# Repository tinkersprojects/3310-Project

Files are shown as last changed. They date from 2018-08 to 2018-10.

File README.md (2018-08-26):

# 3310 Project
The goal of the project is to make a working Nokia 3310 that works with today's tech. The device will be as similar as the original including the screen and body (case). It is unknown what process will be in the finished device but the first will have an ESP32. The ESP32 has both Bluetooth and WiFi which will be used to connect to a smartphone as an extension accessory. 

From the Nokia 3310, the user will be able to make/receive calls and SMS/text messages as well as play original games and all other good features. Additional features like social networking will come later. A micro USB port is used for charging, programming and debugging of the ESP32.

This first prototype is very basic to see which areas would need the most amount of work and to see if this project is worth continuing. There are features missing and features that will not be apart of the device. This prototype will look mostly at getting the LCD, keypad and Bluetooth/WiFi working.

**Get involved, [contact me](https://tinkersprojects.com/contact-me/)**

**See my other projects, [https://tinkersprojects.com/](https://tinkersprojects.com/)**

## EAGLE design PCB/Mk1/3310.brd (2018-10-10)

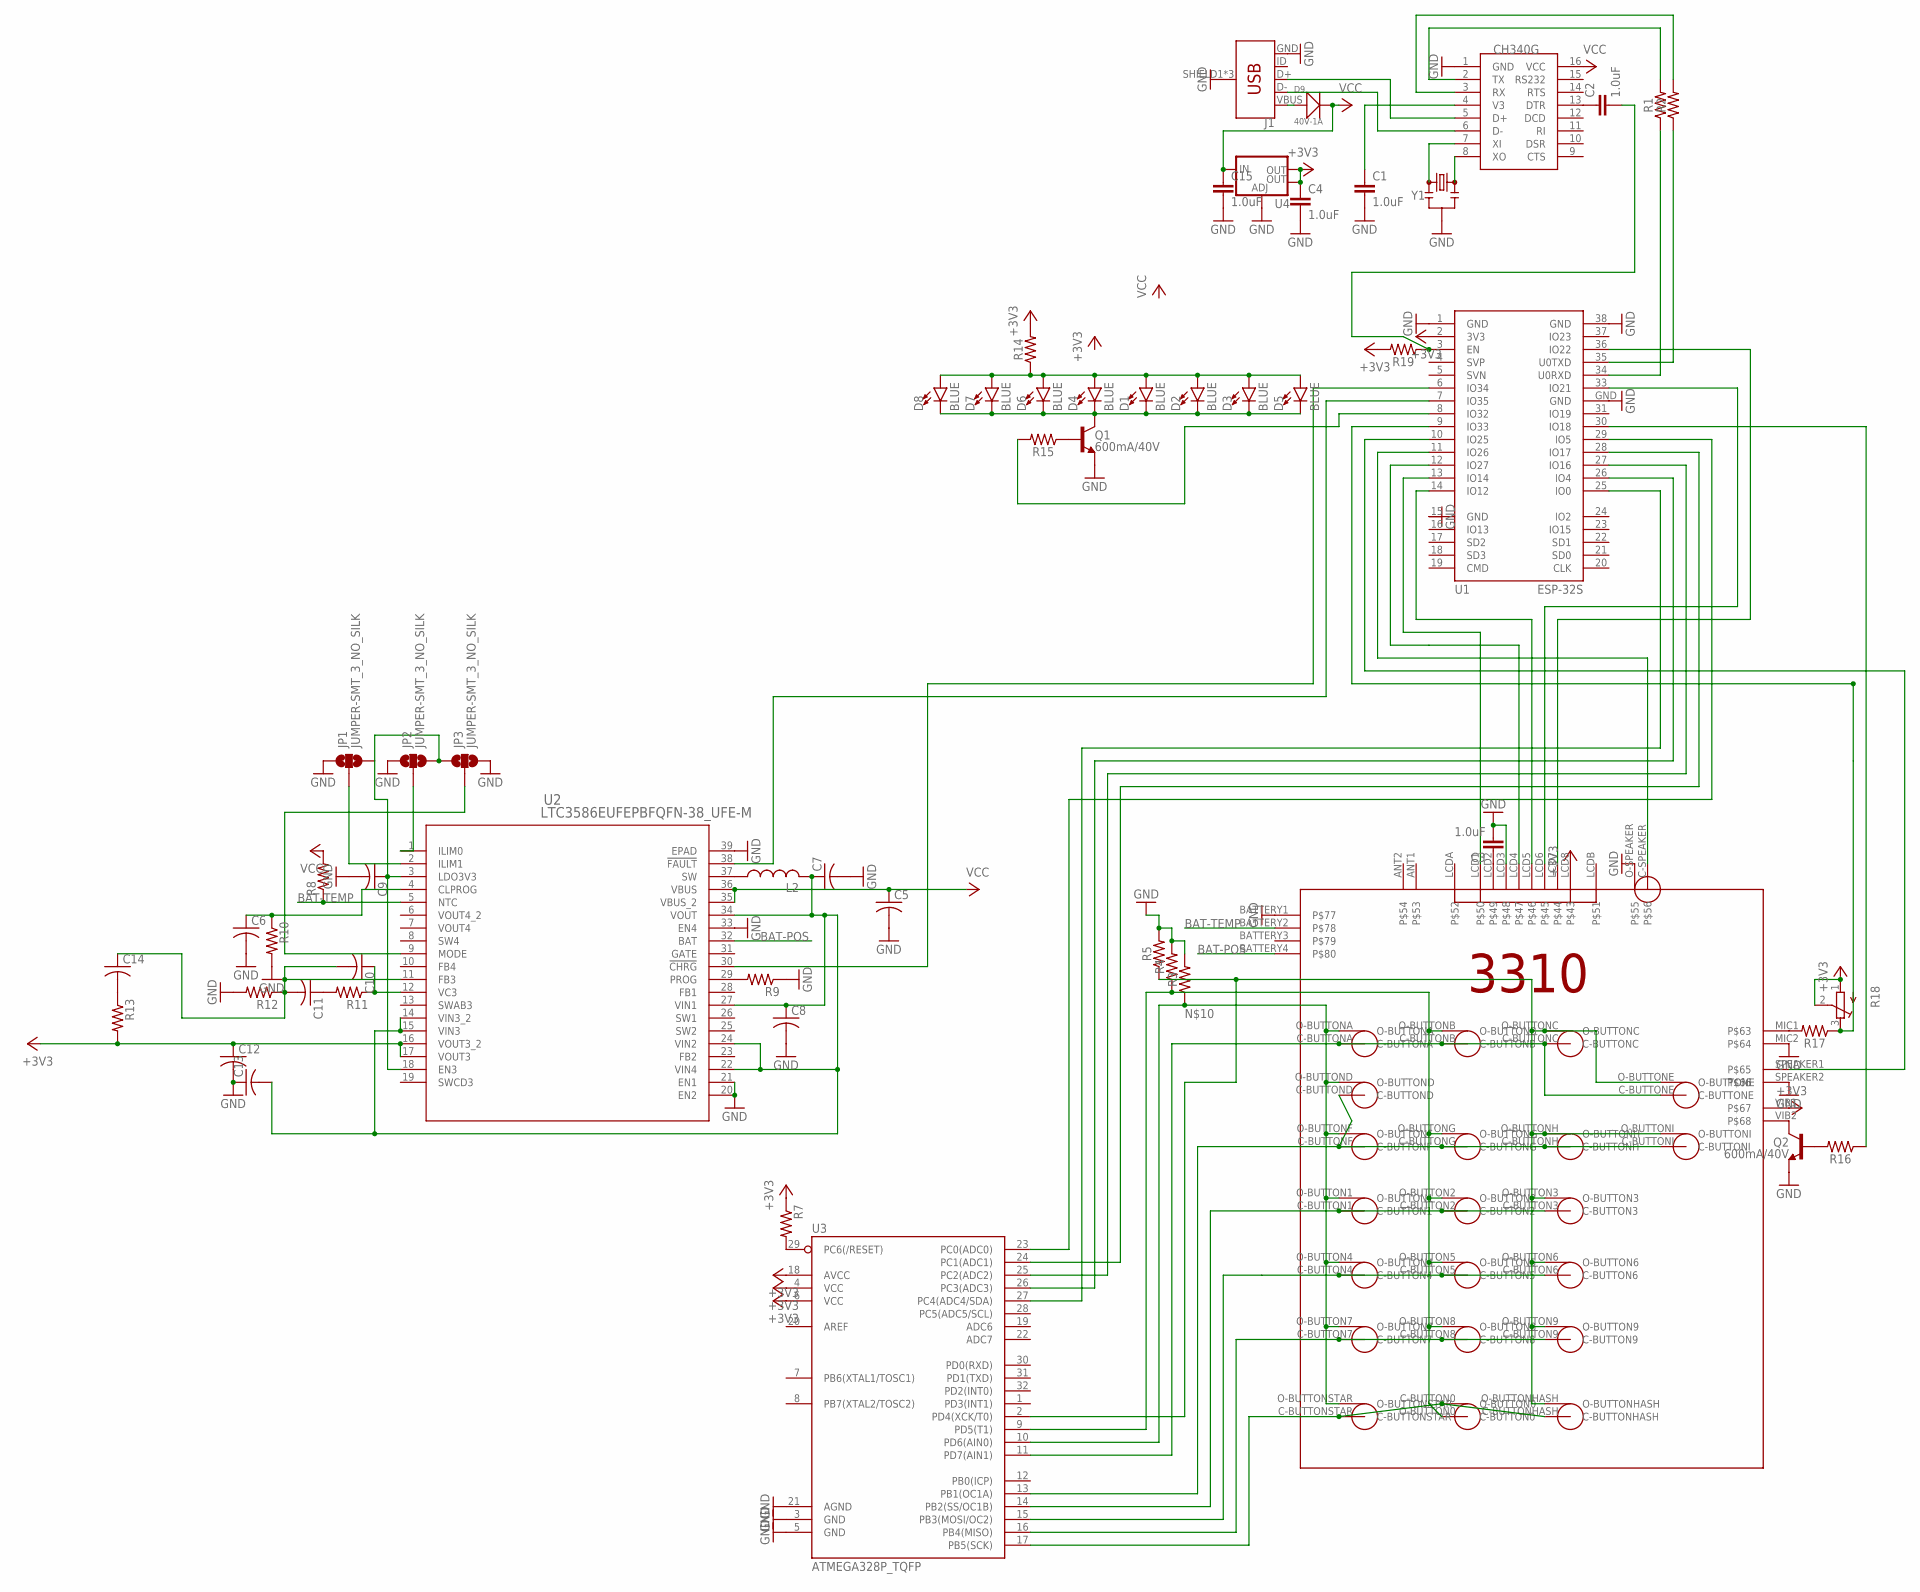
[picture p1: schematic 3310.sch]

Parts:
C1, C2, C3, C4, C15: 1.0uF; 0805
C5, C6, C7, C8, C9, C10, C11, C12, C13, C14: C-USC0805K; C0805K
D1, D2, D3, D4, D5, D6, D7, D8: BLUE; LED-1206
D9: 40V-1A; DO-214AC
J1: USB_MICRO-BREDUCED_PASTE; USB-B-MICRO-SMD_RED_PASTE
JP1, JP2, JP3: JUMPER-SMT_3_NO_SILK; SMT-JUMPER_3_NO_SILK
L2: L-USL3216C; L3216C
Q1, Q2: 600mA/40V; SOT23-3
R1, R2, R3, R4, R5, R14, R15, R16, R17, R19: 0805
R7, R8, R9, R10, R11, R12, R13: R-US_R0805; R0805
R18: R-TRIMM3103; RTRIM3103
U1: ESP-32S
U2: LTC3586EUFEPBFQFN-38_UFE-M; QFN-38_UFE-M
U3: ATMEGA328P_TQFP; TQFP32-08
U4: V_REG_LM1117SOT223; SOT223
U$1: 3310NOJACKANDSIM
U$2: CH340G; SOIC16
Y1: RESONATORSMD-3.2X1.3; RESONATOR-SMD-3.2X1.3

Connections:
+3V3: C4.1, C12.1, R7.1, R13.2, R14.2, R18.1 (A), R18.2 (S), R19.2, U1.2 (3V3), U2.16 (VOUT3_2), U2.17 (VOUT3), U3.4 (VCC), U3.6 (VCC), U3.18 (AVCC), U4.2 (OUT), U4.4 (OUT), U$1.LCD8, U$1.VIB1
BAT-POS: U2.32 (BAT), U$1.BATTERY4
BAT-TEMP: R8.1, U2.5 (NTC), U$1.BATTERY2
GND: C1.2, C3.2, C4.2, C5.2, C6.2, C7.2, C8.2, C9.2, C12.2, C13.1, C15.2, J1.GND, J1.SHIELD1 (SHIELD), J1.SHIELD2 (SHIELD), J1.SHIELD3 (SHIELD), JP1.1, JP2.1, JP3.3, Q1.2 (E), Q2.2 (E), R3.2, R4.2, R5.2, R9.1, R10.2, R12.2, U1.1 (GND), U1.15 (GND), U1.38 (GND), U1.GND, U2.20 (EN2), U2.21 (EN1), U2.33 (EN4), U2.39 (EPAD), U3.3 (GND), U3.5 (GND), U3.21 (AGND), U4.1 (ADJ), U$1.BATTERY1, U$1.LCD3, U$1.MIC2, U$1.O-SPEAKER, U$1.SPEAKER2, U$2.1 (GND), Y1.2
unnamed: J1.D-, U$2.6 (D-)
unnamed: D1.A, D2.A, D3.A, D4.A, D5.A, D6.A, D7.A, D8.A, R14.1
unnamed: U3.17 (PB5(SCK)), U$1.C-BUTTON0 (O-BUTTON0), U$1.C-BUTTONHASH, U$1.C-BUTTONSTAR
unnamed: U3.16 (PB4(MISO)), U$1.C-BUTTON7, U$1.C-BUTTON8, U$1.C-BUTTON9
unnamed: U3.15 (PB3(MOSI/OC2)), U$1.C-BUTTON4, U$1.C-BUTTON5, U$1.C-BUTTON6
unnamed: U3.14 (PB2(SS/OC1B)), U$1.C-BUTTON1, U$1.C-BUTTON2, U$1.C-BUTTON3
unnamed: U3.13 (PB1(OC1A)), U$1.C-BUTTOND, U$1.C-BUTTONF, U$1.C-BUTTONG, U$1.C-BUTTONH, U$1.C-BUTTONI
unnamed: R5.1, U3.2 (PD4(XCK/T0)), U$1.O-BUTTON3, U$1.O-BUTTON6, U$1.O-BUTTON9, U$1.O-BUTTONC, U$1.O-BUTTONE, U$1.O-BUTTONH, U$1.O-BUTTONHASH, U$1.O-BUTTONI
unnamed: U3.11 (PD7(AIN1)), U$1.C-BUTTONA, U$1.C-BUTTONB, U$1.C-BUTTONC, U$1.C-BUTTONE
unnamed: R3.1, U3.10 (PD6(AIN0)), U$1.O-BUTTON1, U$1.O-BUTTON4, U$1.O-BUTTON7, U$1.O-BUTTONA, U$1.O-BUTTOND, U$1.O-BUTTONF, U$1.O-BUTTONSTAR
unnamed: R4.1, U3.9 (PD5(T1)), U$1.O-BUTTON0 (C-BUTTON0), U$1.O-BUTTON2, U$1.O-BUTTON5, U$1.O-BUTTON8, U$1.O-BUTTONB, U$1.O-BUTTONG
unnamed: J1.D+, U$2.5 (D+)
unnamed: D9.1 (+), J1.VBUS
unnamed: U$2.8 (XO), Y1.3
unnamed: U$2.7 (XI), Y1.1
unnamed: C1.1, U$2.4 (V3)
unnamed: C2.1, U$2.13 (DTR)
unnamed: C2.2, R19.1, U1.3 (EN)
unnamed: R1.2, U$2.2 (TX)
unnamed: R2.2, U$2.3 (RX)
unnamed: R1.1, U1.34 (U0RXD)
unnamed: R2.1, U1.35 (U0TXD)
unnamed: U1.14 (IO12), U$1.LCD5
unnamed: C3.1, U$1.LCD2
unnamed: U1.13 (IO14), U$1.LCD1
unnamed: U1.12 (IO27), U$1.LCD4
unnamed: U1.36 (IO22), U$1.LCD7
unnamed: U1.33 (IO21), U$1.LCD6
unnamed: R9.2, U2.29 (PROG)
unnamed: C6.1, R10.1, U2.4 (CLPROG)
unnamed: L2.1, U2.37 (SW)
unnamed: C14.2, R13.1
unnamed: C9.1, JP1.3, JP2.3, JP3.1, U2.3 (LDO3V3), U2.18 (EN3)
unnamed: U1.7 (IO35), U2.38 (!FAULT)
unnamed: C10.1, R11.1, U2.12 (VC3)
unnamed: C11.1, R11.2
unnamed: C10.2, C11.2, C14.1, R12.1, U2.11 (FB3)
unnamed: JP2.2, U2.1 (ILIM0)
unnamed: C7.1, C8.1, C13.2, L2.2, U2.14 (VIN3_2), U2.15 (VIN3), U2.22 (VIN4), U2.24 (VIN2), U2.27 (VIN1), U2.34 (VOUT)
unnamed: JP1.2, U2.2 (ILIM1)
unnamed: U1.6 (IO34), U2.30 (!CHRG)
unnamed: U1.29 (IO5), U3.23 (PC0(ADC0))
unnamed: U1.28 (IO17), U3.24 (PC1(ADC1))
unnamed: R7.2, U3.29 (PC6(/RESET))
unnamed: U1.27 (IO16), U3.25 (PC2(ADC2))
unnamed: U1.26 (IO4), U3.26 (PC3(ADC3))
unnamed: U1.25 (IO0), U3.27 (PC4(ADC4/SDA))
unnamed: D1.C, D2.C, D3.C, D4.C, D5.C, D6.C, D7.C, D8.C, Q1.3 (C)
unnamed: Q1.1 (B), R15.1
unnamed: R15.2, U1.8 (IO32)
unnamed: Q2.3 (C), U$1.VIB2
unnamed: Q2.1 (B), R16.2
unnamed: R16.1, U1.30 (IO18)
unnamed: JP3.2, U2.9 (MODE)
unnamed: R17.2, U$1.MIC1
unnamed: R17.1, R18.3 (E), U1.9 (IO33)
unnamed: U1.11 (IO26), U$1.C-SPEAKER
unnamed: U1.10 (IO25), U$1.SPEAKER1
VCC: C5.1, C15.1, D9.2 (-), R8.2, U2.35 (VBUS_2), U2.36 (VBUS), U4.3 (IN), U$2.16 (VCC)

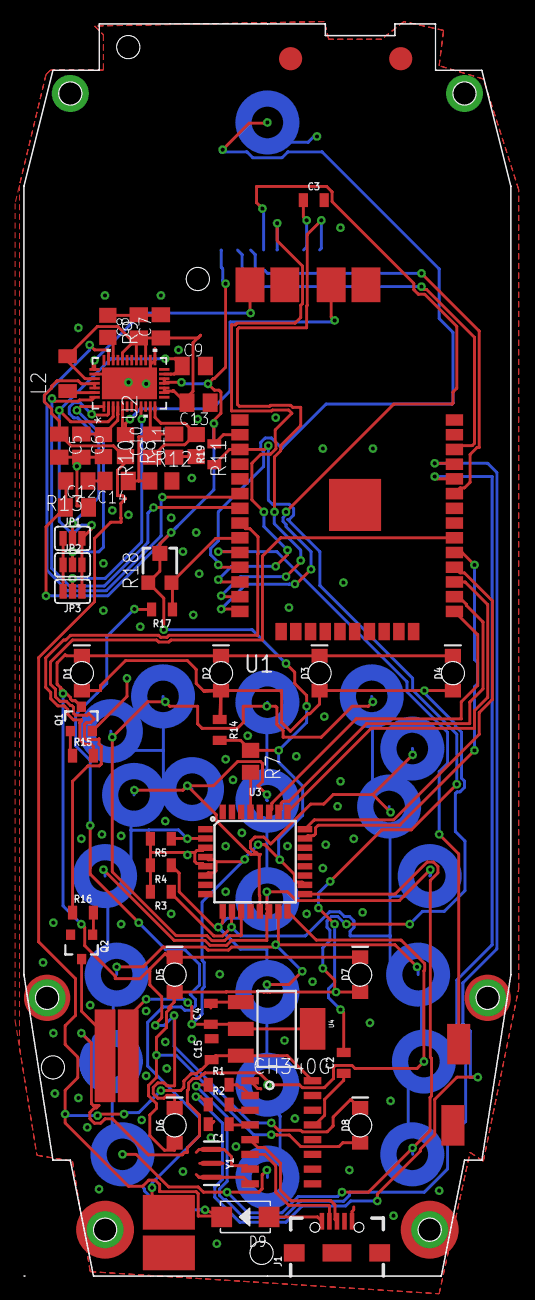
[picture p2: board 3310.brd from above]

Board: 2 copper layers, 42.0 x 108.0 mm, 56 parts (1 on the bottom side), 63 nets.

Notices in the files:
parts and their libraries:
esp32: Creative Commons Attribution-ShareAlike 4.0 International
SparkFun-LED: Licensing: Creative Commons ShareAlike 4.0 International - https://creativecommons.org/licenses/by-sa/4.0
